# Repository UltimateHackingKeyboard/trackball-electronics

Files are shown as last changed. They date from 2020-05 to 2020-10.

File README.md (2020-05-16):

Ultimate Hacking Keyboard trackball module
==========================================

Contained are the schematics and board layout KiCad files for the [Ultimate Hacking Keyboard](https://ultimatehackingkeyboard.com/) trackball module.

Make sure to clone this repo with:

`git clone --recursive git@github.com:UltimateHackingKeyboard/trackball-electronics.git`

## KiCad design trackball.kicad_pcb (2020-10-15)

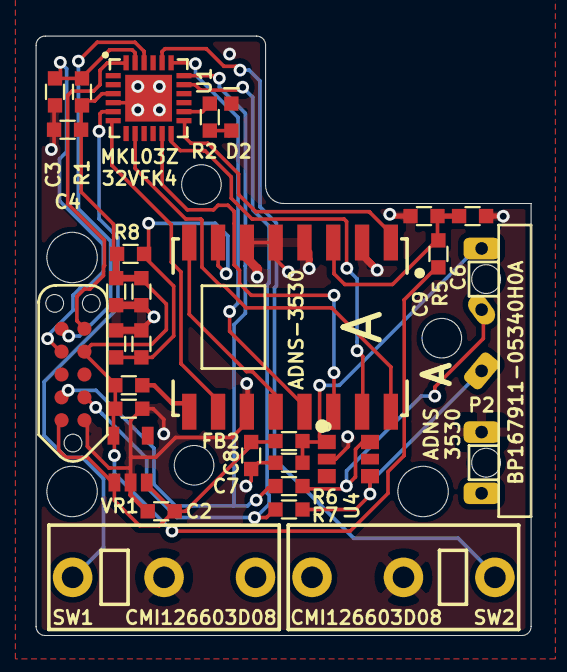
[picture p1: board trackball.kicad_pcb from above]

Board: 2 copper layers, 27.5 x 33.3 mm, 29 parts (0 on the bottom side), 25 nets.

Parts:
C1, C2, C6, C10, C12: 1uF; SM0603
C3, C4, C7, C8: 0.1uF; SM0603
C5, C9, C11: 10nF; SM0603
D2: LED; SM0603_Diode
FB2: FERRITE_BEAD; SM0603
P1: CONN_10; Tag_Connect_2x5_Header_With_No_Legs_Parallel_Numbering
P2: CONN_5; UHK_Male_Pogo_Pin_v2_trackball
R1: 5.1K; SM0603
R2: 330; SM0603
R3, R5, R8: 5.6; SM0603
R6, R7: 33; SM0603
SW1, SW2: CMI126603D08
U1: MKL03Z32VFK4; QFN-24-1EP_4x4mm_Pitch0.5mm
U2: ADNS-3530
U4: ESD; SC-74-TVS
VR1: MIC5504-3.3YM5; SOT-23-5

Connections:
+3V3: C1.2, C4.2, C5.2, C12.2, P1.7, R1.1, R3.2, R5.2, R8.2, U1.3, VR1.5
+5V: C2.2, C8.2, FB2.2, P1.2, VR1.1, VR1.3
/ADNS_AVDD: C10.2, C11.2, R8.1, U2.10
/ADNS_VDD: C6.2, C9.2, R5.1, U2.14
/LED+: R3.1, U2.8
/LED-: U2.5, U2.9
/MISO: U1.8, U2.1
/MOSI: U1.11, U2.3
/MOTION: U1.19, U2.4
/NCS: U1.13, U2.16
/RESET: C3.2, P1.8, R1.2, U1.23
/SCK: U1.12, U2.2
/SCL: P1.3, R7.1, U1.17
/SCL_BOTTOM: P2.3, R7.2, U4.4
/SDA: P1.4, R6.1, U1.18
/SDA_BOTTOM: P2.2, R6.2, U4.5
/SHTDWN: U1.6, U2.7
/SW1: SW1.1, U1.5
/SW2: SW2.1, U1.20
/SWDCLK: P1.10, U1.22
/SWDIO: P1.9, U1.24
/TEST_LED: R2.2, U1.14
/TEST_LED_R: D2.2, R2.1
/VCC_BOTTOM: C7.2, FB2.1, P2.1, U4.1
GND: C1.1, C2.1, C3.1, C4.1, C5.1, C6.1, C7.1, C8.1, C9.1, C10.1, C11.1, C12.1, D2.1, P1.1, P2.4, SW1.2, SW2.2, U1.4, U1.25, U2.6, U2.11, U2.12, U2.13, U2.15, U4.2, VR1.2

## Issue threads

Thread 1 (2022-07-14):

Is it possible to have the 3D model of the enclosure as well?

rudyferraro, 2022-07-14:
Hello,

Is it possible to have the 3D model of the enclosure as well? It will help creating custom trackball modules.

Thanks,
Cheers,
Rudy

mondalaci, 2022-07-14:
Hi Rudy,

We plan to create a module development kit eventually, but in the meantime, [our policy](https://ultimatehackingkeyboard.com/knowledgebase?q=cad) is to not share the 3D CAD files of parts that are in production.

However, we want to make improvements to the trackball module. Please shoot an email to support@ultimatehackingkeyboard.com and let us know what you're up to.

Closed 2022-07-14.

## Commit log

2019-07-03 Import mechanical PCB.
    [trackball.kicad_pcb]
2019-07-03 Add components to the board.
    [trackball.kicad_pcb]
2019-07-03 Add keepout areas.
    [trackball.kicad_pcb]
2019-07-05 Add sch to project.
    [trackball.kicad_pcb, trackball.sch]
2019-07-07 Improve silk screen.
    [trackball.kicad_pcb]
2019-07-07 Update description
    [trackball.kicad_pcb]
2019-07-08 Manual merge trick.
    [trackball.kicad_pcb]
2019-07-08 Footprint library references modified.
    [trackball.kicad_pcb, trackball.sch]
2019-07-08 Components added.
    [trackball.kicad_pcb]
2019-07-08 Update contour.
    [trackball.kicad_pcb]
2019-07-09 First final version without test points.
    [trackball.kicad_pcb, trackball.sch]
2019-07-10 Remove test points.
    [trackball.sch]
2019-07-10 Visible values on silkscreen.
    [trackball.kicad_pcb]
2019-07-17 Change UPA header pinout.
    [trackball.kicad_pcb, trackball.sch]
2019-07-21 Update microswitch footprints.
    [trackball.kicad_pcb]
2019-08-05 Improve silk screen. Feature 5.6 instead of 5R6.
    [trackball.kicad_pcb, trackball.sch]
2019-08-05 Update ADNS-3530 footprint.
    [trackball.kicad_pcb]
2019-08-05 Bump version number to 1.0.0
    [trackball.kicad_pcb, trackball.sch]
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2019-08-05 Make microswitch values consistent for them to show up as similar BOM components.
    [trackball.kicad_pcb, trackball.sch]
2019-08-05 Display optical sensor and microswitch part number on the silk screen.
    [trackball.kicad_pcb]
2019-08-07 Display part number for the pogo pin connector.
    [trackball.kicad_pcb]
2019-08-07 Add UHK logo.
    [trackball.kicad_pcb]
2019-08-09 Bump version number to 1.1.0
    [trackball.kicad_pcb, trackball.sch]
2019-08-09 Add UPA14 text.
    [trackball.kicad_pcb]
2019-08-09 Enable additional layers.
    [trackball.kicad_pcb]
2019-08-15 Add clearances around mechanical holes.
    [trackball.kicad_pcb]
2019-08-16 Make pogo pin through hole, make logo virtual, make ESD text visible.
    [trackball.kicad_pcb]
2019-09-10 Update ADNS-3530 footprint and reconnect pads.
    [trackball.kicad_pcb]
2019-10-27 Update microswitch and ADNS modules.
    [trackball.kicad_pcb]
2019-10-27 Add orientation marker circle for the ESD suppressor.
    [trackball.kicad_pcb]
2019-10-27 Bump version number to 1.2.0
    [trackball.kicad_pcb, trackball.sch]
2019-10-27 Show LED value instead of reference designator.
    [trackball.kicad_pcb]
2019-10-27 Update LED module.
    [trackball.kicad_pcb]
2019-12-09 Set the size of all label text size to 0.04 inch.
    [trackball.sch]
2019-12-09 Make the size of all labels 0.04 inch.
    [trackball.sch]
2020-01-24 Make the test LED and its resistor virtual.
    [trackball.kicad_pcb]
2020-03-15 Fix sensor position.
    [trackball.kicad_pcb]
2020-03-15 Update sensor footprint.
    [trackball.kicad_pcb]
2020-03-15 Add additional silk screen content for the sensor.
    [trackball.kicad_pcb]
2020-04-05 Disconnect pin 5 of the pogo pin connector.
    [trackball.kicad_pcb, trackball.sch]
2020-04-12 Update Kailh microswitches.
    [trackball.kicad_pcb]
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2020-05-17 Replace resistors from 4.7K to 5.1K and from 47 to 33 ohms.
    [trackball.kicad_pcb, trackball.sch]
2020-05-17 Remove redudant C13.
    [trackball.kicad_pcb, trackball.sch]
2020-05-17 Remove redundant R4.
    [trackball.kicad_pcb, trackball.sch]
2020-05-17 Fix schematic around R5 and R8.
    [trackball.kicad_pcb, trackball.sch]
2020-05-18 Update board based on CAD.
    [trackball.kicad_pcb]
2020-05-18 Bump version to 1.3.0
    [trackball.kicad_pcb, trackball.sch]
2020-06-06 Reroute board on a shrinked area.
    [trackball.kicad_pcb, trackball.sch]
2020-06-06 Don't route tracks on the part of the board that will be removed.
    [trackball.kicad_pcb]
2020-06-06 Use 8 mil tracks all around.
    [trackball.kicad_pcb]
2020-06-06 Move the MCU closer to the center of the board.
    [trackball.kicad_pcb, trackball.sch]
2020-06-06 Minimize board outline.
    [trackball.kicad_pcb]
2020-06-06 Add back logo to the board.
    [trackball.kicad_pcb]
2020-06-06 Spruce up silk screen.
    [trackball.kicad_pcb]
2020-06-06 Rename microswitch reference designators to SW1 and SW2.
    [trackball.kicad_pcb, trackball.sch]
2020-06-06 Move test LED components farther from the nearby boss.
    [trackball.kicad_pcb]
2020-06-06 Tweak pogo pin pad.
    [trackball.kicad_pcb]
2020-06-06 Make the width of the upper region of the PCB 12.75 mm.
    [trackball.kicad_pcb]
2020-06-06 Set the height of the board precisely to 33.3 mm.
    [trackball.kicad_pcb]
2020-06-06 Tweak silk screen.
    [trackball.kicad_pcb]
2020-06-06 Don't cover R2 and D2 with paste.
    [trackball.kicad_pcb, trackball.sch]
2020-06-06 Resolve DRC issue by repositioning C8.
    [trackball.kicad_pcb]
2020-06-06 Clean up minor silk screen issues.
    [trackball.kicad_pcb]
2020-06-06 Bump board version to 1.4.0
    [trackball.kicad_pcb, trackball.sch]
2020-06-10 Capitalize UGL schematic library name.
    [trackball.sch]
2020-06-10 Capitalize UGL library name for the board.
    [trackball.kicad_pcb]
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2020-09-07 Make silk screen easier to read and improve polarization marks.
    [trackball.kicad_pcb]
2020-10-13 Improve silk screen for AOI.
    [trackball.kicad_pcb]
2020-10-13 Bump version to 1.4.1
    [trackball.kicad_pcb, trackball.sch]
2020-10-15 Move away tracks from the keepout areas of screws as much as possible.
    [trackball.kicad_pcb]
2020-10-15 Bump version to 1.5.0
    [trackball.kicad_pcb, trackball.sch]
